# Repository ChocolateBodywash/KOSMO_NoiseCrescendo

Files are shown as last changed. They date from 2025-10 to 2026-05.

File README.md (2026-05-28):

## KOSMO Format Noise Crescendo

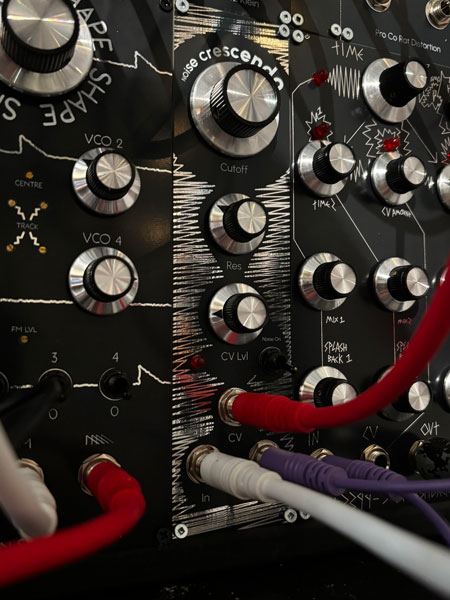
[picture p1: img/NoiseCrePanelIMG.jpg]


This is a compact module designed to produce noise crescendos for transitions, sweeps, and other crazy sounds. It’s built around a simple transistor noise circuit feeding into a low-pass filter.
The filter itself is adapted from Look Mum No Computer’s Synth Voice on a Breadboard video:

Look Mum No Computer’s Synth Voice on a Breadboard video (https://www.youtube.com/watch?v=GsTGu2V7tcU&t=2612s)

I adjusted a few component values to adjust the resonance and CV behaviour.

### Can it just be used as a filter?
Yes. With a passive summing mixer, an input jack, and an on/off switch for the noise, this becomes a straightforward low-pass filter.
LM13700s cost $4 USD on Tayda. In Canadian terms, that’s… let’s just say ‘not cheap,’ so I prefer modules that pull double duty.

---

Note: This was created by a hobbyist with no formal engineering training outside various late night YouTube binges. 
I’ve confirmed these designs to work but I make no guarantees on the design working efficiently.. or working at all.

Credit: Analog Output (Richard Holmes) for footprint libraries and front panel templates.

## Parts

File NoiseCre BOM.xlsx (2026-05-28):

Noise Crescendo
Reference | Value | Package | Qty
C1,C13 | 1uF | Box Style Film Capacitor | 2
C2,C3 | 47uF | Electrolytic Capacitor | 2
C4,C5,C6,C7,C8,C9 | 0.1uF | Ceramic Disc Capacitor | 6
C10 | 100nF | Box Style Film Capacitor | 1
C11 | 470pF | Ceramic Disc Capacitor | 1
C12 | 220pF | Ceramic Disc Capacitor | 1
D1,D2 | 1N5819 | Diode_THT:D_DO-41_SOD81_P10.16mm_Horizontal | 2
D5 | LED | LED 5.0mm | 1
E1 | Conn_01x10_Pin | 4ms_Connector:Pins_2x05_2.54mm_TH_EurorackPower_Shrouded | 1
J1 | Out | Jack_6.35mm | 1
J2 | CV In | Jack_6.35mm | 1
J3,J4 | Conn_01x06 | Connector_PinHeader_2.54mm:PinHeader_1x06_P2.54mm_Vertical | 2
J5 | In | Jack_6.35mm | 1
Q1 | BC548 | Package_TO_SOT_THT:TO-92_Inline_Wide | 1
Q2,Q3 | 2N3906 | Package_TO_SOT_THT:TO-92_Inline_Wide | 2
R1,R2,R5,R10,R13,R15,R18,R25,R29,R30 | 100K | Metal Film 1/4 Resistor | 10
R3,R4 | 10 | Metal Film 1/4 Resistor | 2
R6,R14,R16,R23,R24 | 220 | Metal Film 1/4 Resistor | 5
R7,R11,R12,R17,R21, R22,R26 | 10K | Metal Film 1/4 Resistor | 7
R8 | 470K | Metal Film 1/4 Resistor | 1
R9,R19,R27 | 1K | Metal Film 1/4 Resistor | 3
R20 | 47K | Metal Film 1/4 Resistor | 1
R28 | 6.8K | Metal Film 1/4 Resistor | 1
SW1 | SW_DPDT_x2 | DPDT-toggle-switch | 1
U1 | TL074 | DIP-14_W7.62mm_Socket_LongPads | 1
U2 | LM13700 | DIP-16_W7.62mm_Socket_LongPads | 1
VR1 | B100K Cutoff | Potentiometer_Alpha_RD901F-40-00D_Single_Vertical | 1
VR2 | B100K CV | Potentiometer_Alpha_RD901F-40-00D_Single_Vertical | 1
VR3 | B100K RES | Potentiometer_Alpha_RD901F-40-00D_Single_Vertical | 1

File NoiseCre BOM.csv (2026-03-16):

Reference | Value | Datasheet | Package | Qty
C1,C13 | 1uF | ~ | Box Style Film Capacitor | 2
C2,C3 | 47uF | ~ | Electrolytic Capacitor | 2
C4,C5,C6,C7,C8,C9 | 0.1uF | ~ | Ceramic Disc Capacitor | 6
C10 | 100nF | ~ | Box Style Film Capacitor | 1
C11 | 470pF | ~ | Ceramic Disc Capacitor | 1
C12 | 220pF | ~ | Ceramic Disc Capacitor | 1
D1,D2 | 1N5819 | http://www.vishay.com/docs/88525/1n5817.pdf | Diode_THT:D_DO-41_SOD81_P10.16mm_Horizontal | 2
D5 | LED | ~ | LED 5.0mm | 1
E1 | Conn_01x10_Pin | ~ | 4ms_Connector:Pins_2x05_2.54mm_TH_EurorackPower_Shrouded | 1
J1 | Out | ~ | Jack_6.35mm | 1
J2 | CV In | ~ | Jack_6.35mm | 1
J3,J4 | Conn_01x06 | ~ | Connector_PinHeader_2.54mm:PinHeader_1x06_P2.54mm_Vertical | 2
J5 | In | ~ | Jack_6.35mm | 1
Q1 | BC548 | https://www.onsemi.com/pub/Collateral/BC550-D.pdf | Package_TO_SOT_THT:TO-92_Inline_Wide | 1
Q2,Q3 | 2N3906 | https://www.onsemi.com/pub/Collateral/2N3906-D.PDF | Package_TO_SOT_THT:TO-92_Inline_Wide | 2
R1,R2,R5,R10,R13,R15,R18,R25,R29,R30 | 100K | ~ | Metal Film 1/4 Resistor | 10
R3,R4 | 10 | ~ | Metal Film 1/4 Resistor | 2
R6,R14,R16,R23,R24 | 220 | ~ | Metal Film 1/4 Resistor | 5
R7,R11,R12,R17,R21,R22,R26 | 10K | ~ | Metal Film 1/4 Resistor | 7
R8 | 470K | ~ | Metal Film 1/4 Resistor | 1
R9,R19,R27 | 1K | ~ | Metal Film 1/4 Resistor | 3
R20 | 47K | ~ | Metal Film 1/4 Resistor | 1
R28 | 6.8K | ~ | Metal Film 1/4 Resistor | 1
SW1 | SW_DPDT_x2 | ~ | DPDT-toggle-switch | 1
U1 | TL074 | http://www.ti.com/lit/ds/symlink/tl071.pdf | DIP-14_W7.62mm_Socket_LongPads | 1
U2 | LM13700 | http://www.ti.com/lit/ds/symlink/lm13700.pdf | DIP-16_W7.62mm_Socket_LongPads | 1
VR1 | B100K Cutoff | ~ | Potentiometer_Alpha_RD901F-40-00D_Single_Vertical | 1
VR2 | B100K CV | ~ | Potentiometer_Alpha_RD901F-40-00D_Single_Vertical | 1
VR3 | B100K RES | ~ | Potentiometer_Alpha_RD901F-40-00D_Single_Vertical | 1

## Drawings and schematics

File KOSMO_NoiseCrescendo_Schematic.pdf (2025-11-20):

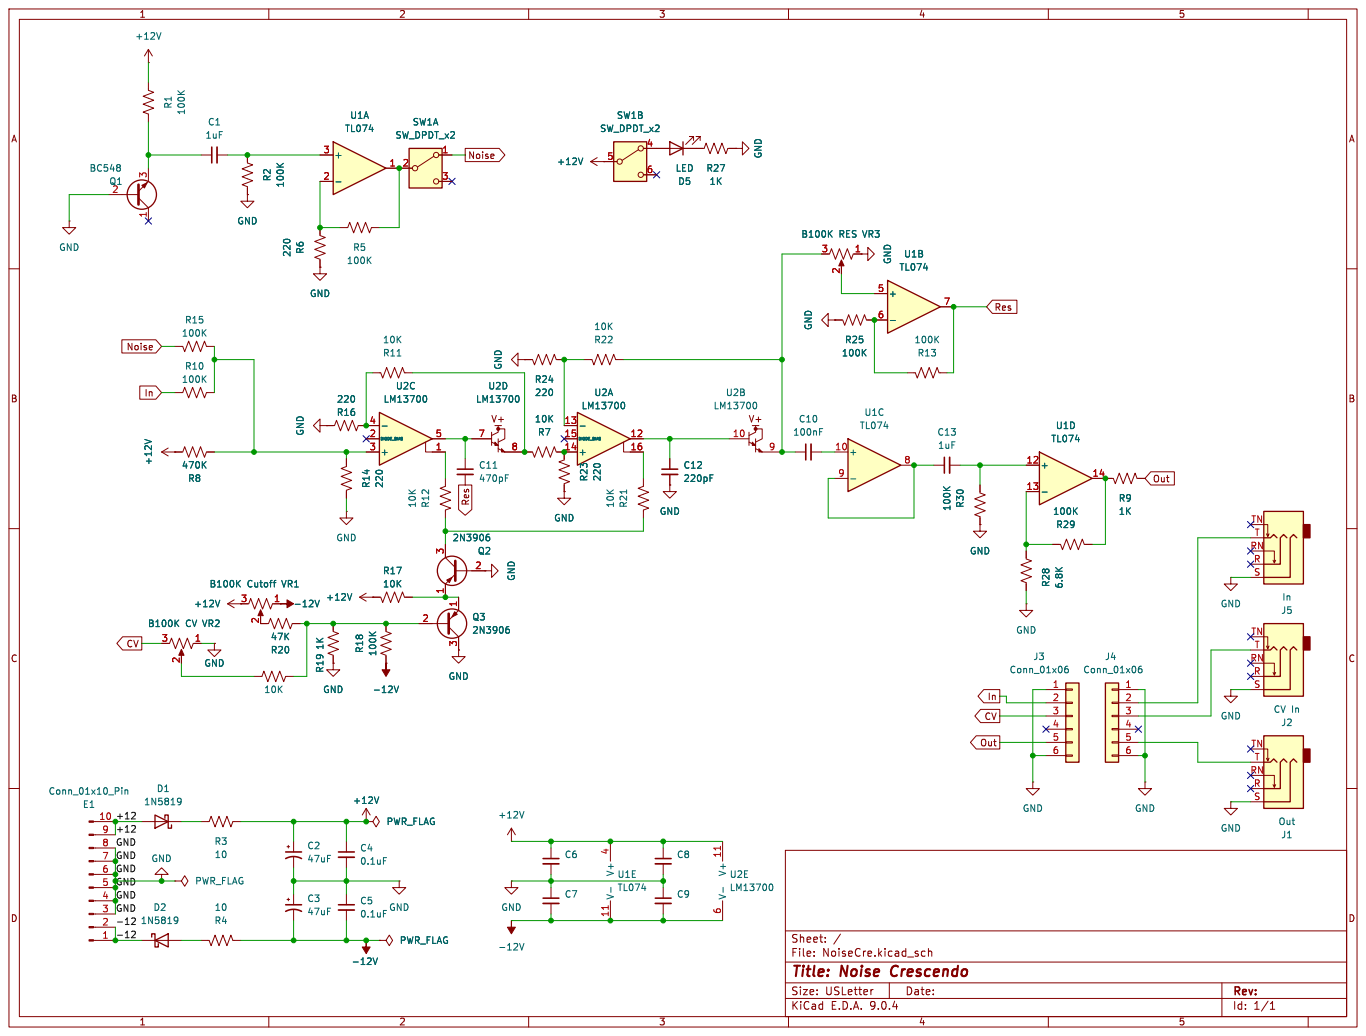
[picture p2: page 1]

File: NoiseCre.kicad_sch Sheet: /
Id: 1/1 Title: Noise Crescendo

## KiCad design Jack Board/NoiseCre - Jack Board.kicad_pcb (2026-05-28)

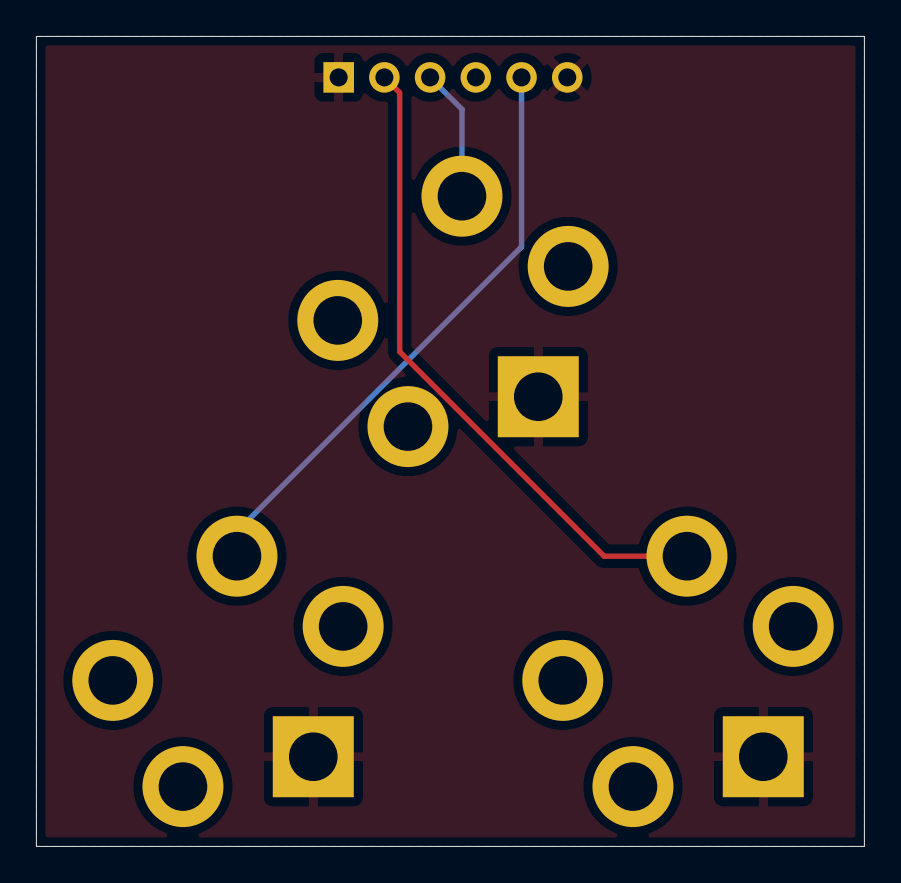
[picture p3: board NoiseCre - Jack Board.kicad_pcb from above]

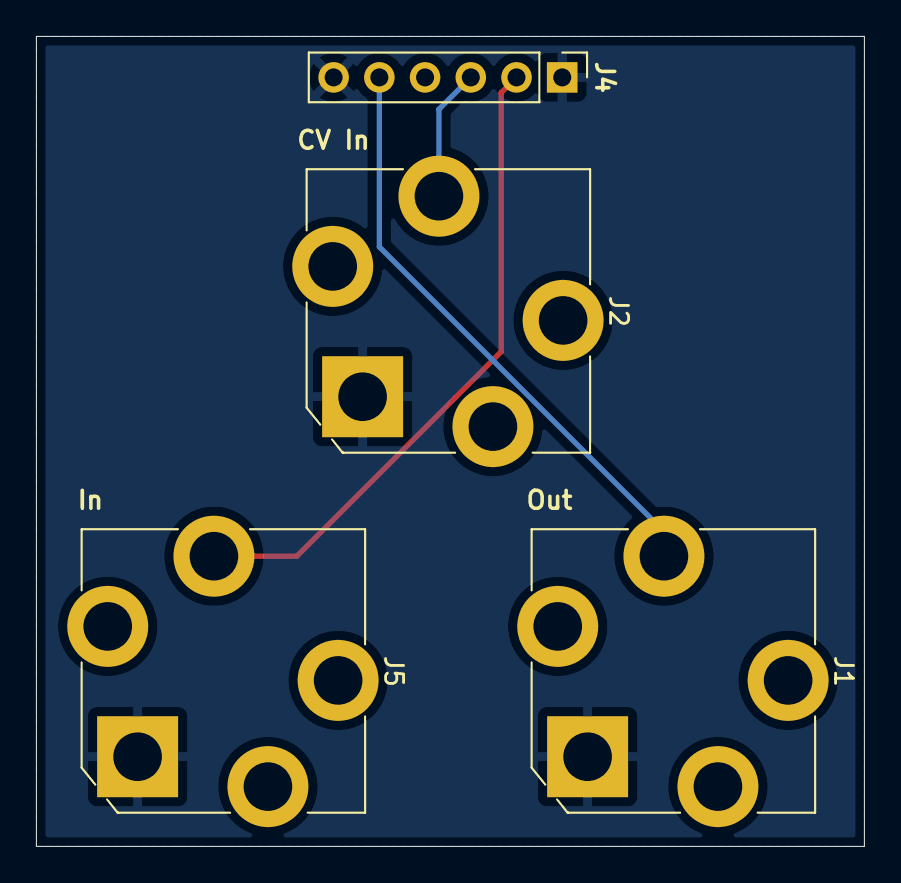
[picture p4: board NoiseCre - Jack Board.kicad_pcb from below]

Board: 2 copper layers, 46.0 x 45.0 mm, 4 parts (4 on the bottom side), 4 nets.

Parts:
J1: Out; Jack_6.35mm_PJ_629HAN
J2: CV In; Jack_6.35mm_PJ_629HAN
J4: Conn_01x06; PinHeader_1x06_P2.54mm_Vertical
J5: In; Jack_6.35mm_PJ_629HAN

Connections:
GND: J1.S, J2.S, J4.1, J4.6, J5.S
unnamed: J4.2, J5.T
unnamed: J2.T, J4.3
unnamed: J1.T, J4.5

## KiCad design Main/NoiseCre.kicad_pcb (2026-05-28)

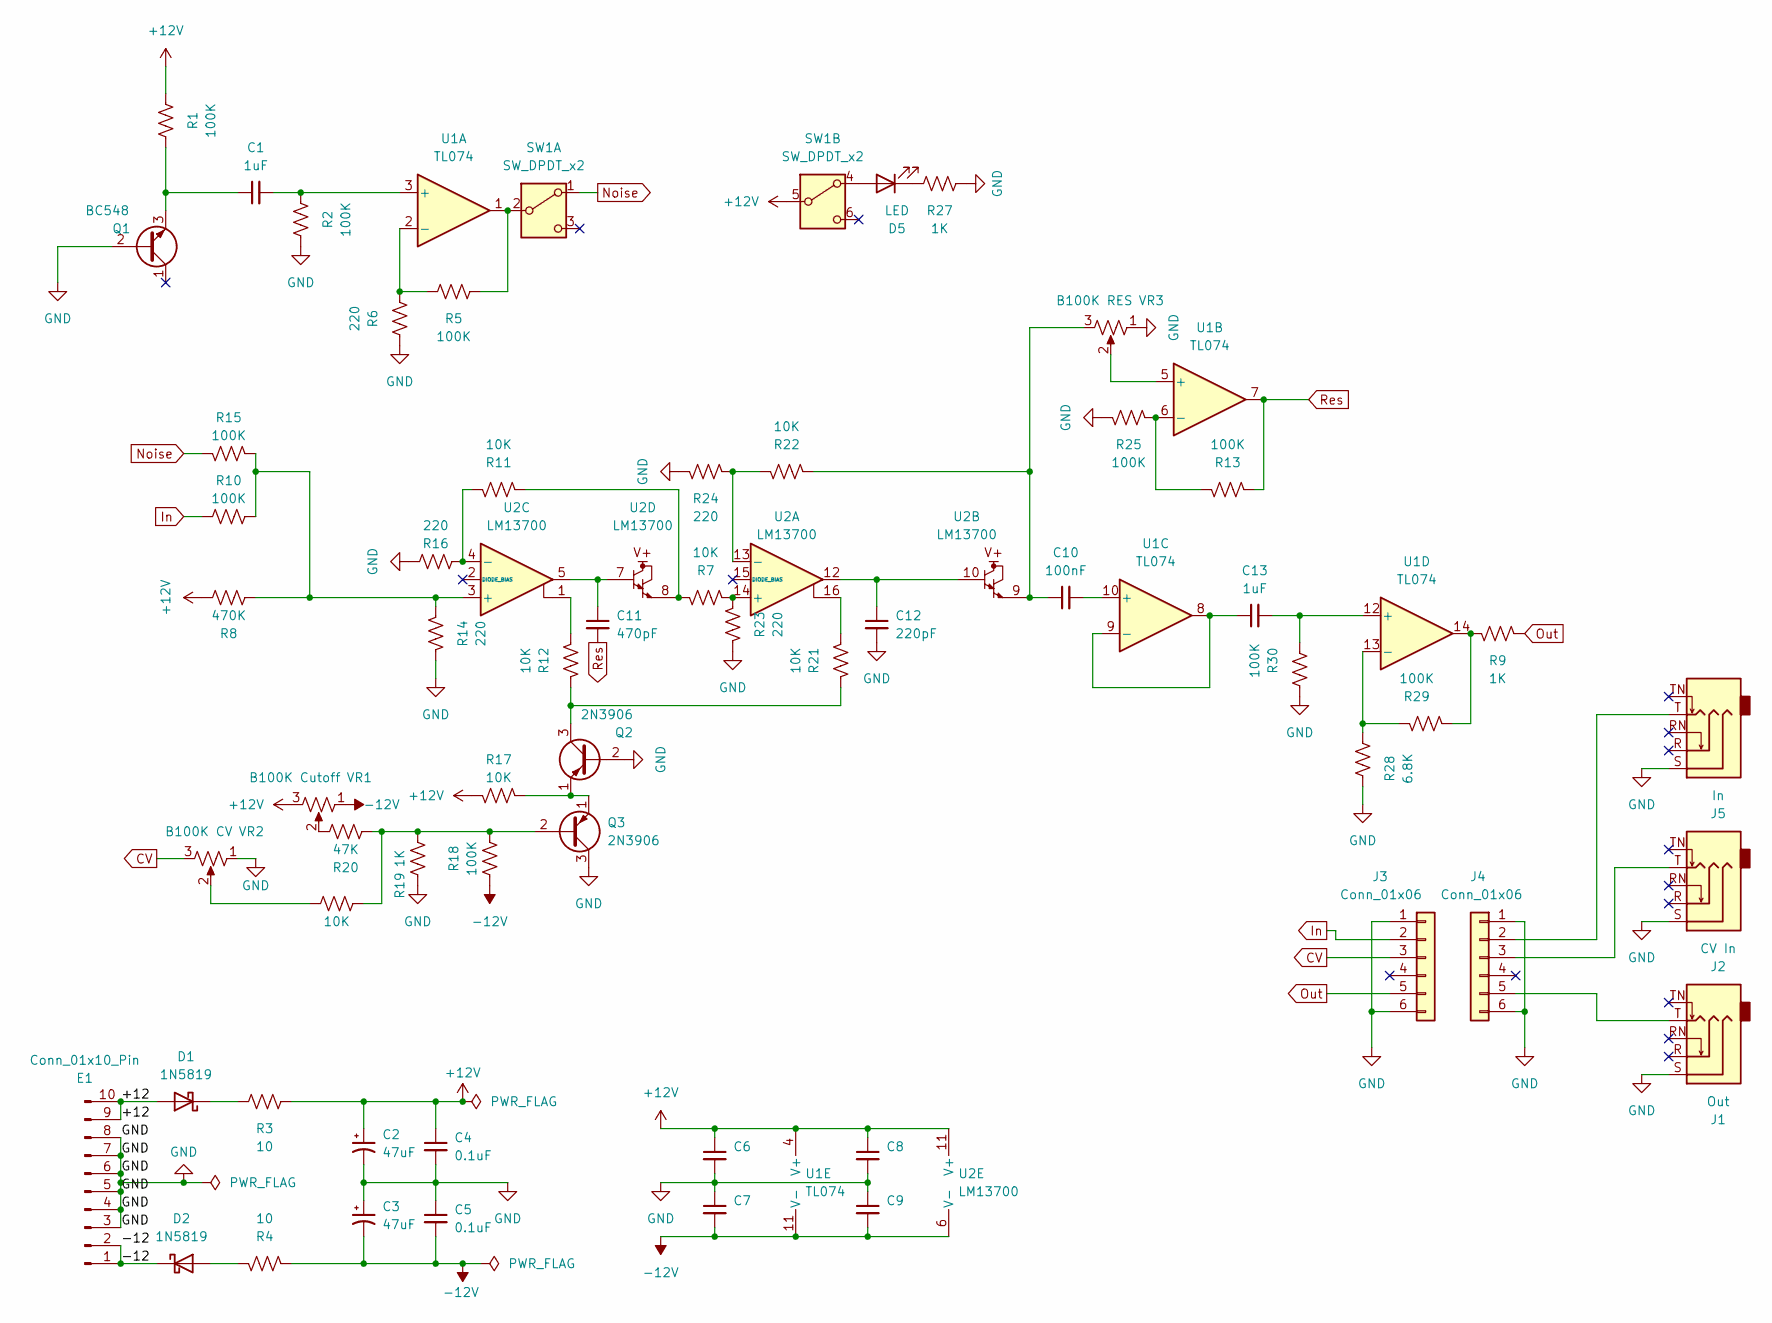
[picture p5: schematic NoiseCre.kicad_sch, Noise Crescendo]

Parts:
C1, C13: 1uF; C_Rect_L7.2mm_W5.5mm_P5.00mm_FKS2_FKP2_MKS2_MKP2
C2, C3: 47uF; CP_Radial_D5.0mm_P2.50mm
C4, C5, C6, C7, C8, C9: 0.1uF; C_Disc_D3.0mm_W1.6mm_P2.50mm
C10: 100nF; C_Rect_L7.2mm_W2.5mm_P5.00mm_FKS2_FKP2_MKS2_MKP2
C11: 470pF; C_Disc_D3.0mm_W1.6mm_P2.50mm
C12: 220pF; C_Disc_D3.0mm_W1.6mm_P2.50mm
D1, D2: 1N5819; D_DO-41_SOD81_P10.16mm_Horizontal
D5: LED; LED_D5.0mm
E1: Conn_01x10_Pin; Pins_2x05_2.54mm_TH_EurorackPower_Shrouded
J1: Out; Jack_6.35mm_PJ_629HAN
J2: CV In; Jack_6.35mm_PJ_629HAN
J3, J4: Conn_01x06; PinHeader_1x06_P2.54mm_Vertical
J5: In; Jack_6.35mm_PJ_629HAN
Q1: BC548; TO-92_Inline_Wide
Q2, Q3: 2N3906; TO-92_Inline_Wide
R1, R2, R5, R10, R13, R15, R18, R25, R29, R30: 100K; R_Axial_DIN0207_L6.3mm_D2.5mm_P10.16mm_Horizontal
R3, R4: 10; R_Axial_DIN0207_L6.3mm_D2.5mm_P10.16mm_Horizontal
R6, R14, R16, R23, R24: 220; R_Axial_DIN0207_L6.3mm_D2.5mm_P10.16mm_Horizontal
R7, R11, R12, R17, R21, R22, R26: 10K; R_Axial_DIN0207_L6.3mm_D2.5mm_P10.16mm_Horizontal
R8: 470K; R_Axial_DIN0207_L6.3mm_D2.5mm_P10.16mm_Horizontal
R9, R19, R27: 1K; R_Axial_DIN0207_L6.3mm_D2.5mm_P10.16mm_Horizontal
R20: 47K; R_Axial_DIN0207_L6.3mm_D2.5mm_P10.16mm_Horizontal
R28: 6.8K; R_Axial_DIN0207_L6.3mm_D2.5mm_P10.16mm_Horizontal
SW1: SW_DPDT_x2; DPDT-toggle-switch-1M-seriesx
U1: TL074; DIP-14_W7.62mm_Socket_LongPads
U2: LM13700; DIP-16_W7.62mm_Socket_LongPads
VR1: B100K Cutoff; Potentiometer_Alpha_RD901F-40-00D_Single_Vertical
VR2: B100K CV; Potentiometer_Alpha_RD901F-40-00D_Single_Vertical
VR3: B100K RES; Potentiometer_Alpha_RD901F-40-00D_Single_Vertical

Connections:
+12V: C2.1, C4.1, C6.1, C8.1, R1.2, R3.2, R8.2, R17.2, SW1.5 (B), U1.4 (V+), U2.11 (V+), VR1.3
-12V: C3.2, C5.2, C7.2, C9.2, R4.2, R18.1, U1.11 (V-), U2.6 (V-), VR1.1
/+12: D1.2 (A), E1.9, E1.10
/-12: D2.1 (K), E1.1, E1.2
CV: J3.3, VR2.3
GND: C2.2, C3.1, C4.2, C5.1, C6.2, C7.1, C8.2, C9.1, C12.2, E1.3, E1.4, E1.5, E1.6, E1.7, E1.8, J1.S, J2.S, J3.1, J3.6, J4.1, J4.6, J5.S, Q1.2 (B), Q2.2 (B), Q3.3 (C), R2.1, R6.2, R14.2, R16.2, R19.1, R23.2, R24.2, R25.2, R27.2, R28.1, R30.2, VR2.1, VR3.1
In: J3.2, R10.1
unnamed: C10.1, R22.2, U2.9, VR3.3
unnamed: C11.1, U2.5, U2.7
unnamed: C12.1, U2.10, U2.12
unnamed: D1.1 (K), R3.1
unnamed: D2.2 (A), R4.1
unnamed: D5.2 (A), SW1.4 (A)
unnamed: D5.1 (K), R27.1
unnamed: J1.T, J4.5
unnamed: J2.T, J4.3
unnamed: J4.2, J5.T
unnamed: C1.1, Q1.3 (E), R1.1
unnamed: Q2.3 (C), R12.1, R21.1
unnamed: Q2.1 (E), Q3.1 (E), R17.1
unnamed: Q3.2 (B), R18.2, R19.2, R20.1, R26.1
unnamed: R7.1, R11.2, U2.8
unnamed: R12.2, U2.1
unnamed: R20.2, VR1.2
unnamed: R21.2, U2.16
unnamed: R26.2, VR2.2
unnamed: R9.2, R29.2, U1.14
unnamed: R5.2, SW1.2 (B), U1.1
unnamed: C1.2, R2.2, U1.3 (+)
unnamed: R5.1, R6.1, U1.2 (-)
unnamed: U1.5 (+), VR3.2
unnamed: R13.1, R25.1, U1.6 (-)
unnamed: C10.2, U1.10 (+)
unnamed: C13.1, U1.8, U1.9 (-)
unnamed: C13.2, R30.1, U1.12 (+)
unnamed: R28.2, R29.1, U1.13 (-)
unnamed: R7.2, R23.1, U2.14 (+)
unnamed: R22.1, R24.1, U2.13 (-)
unnamed: R8.1, R10.2, R14.1, R15.1, U2.3 (+)
unnamed: R11.1, R16.1, U2.4 (-)
Noise: R15.2, SW1.1 (A)
Out: J3.5, R9.1
Res: C11.2, R13.2, U1.7

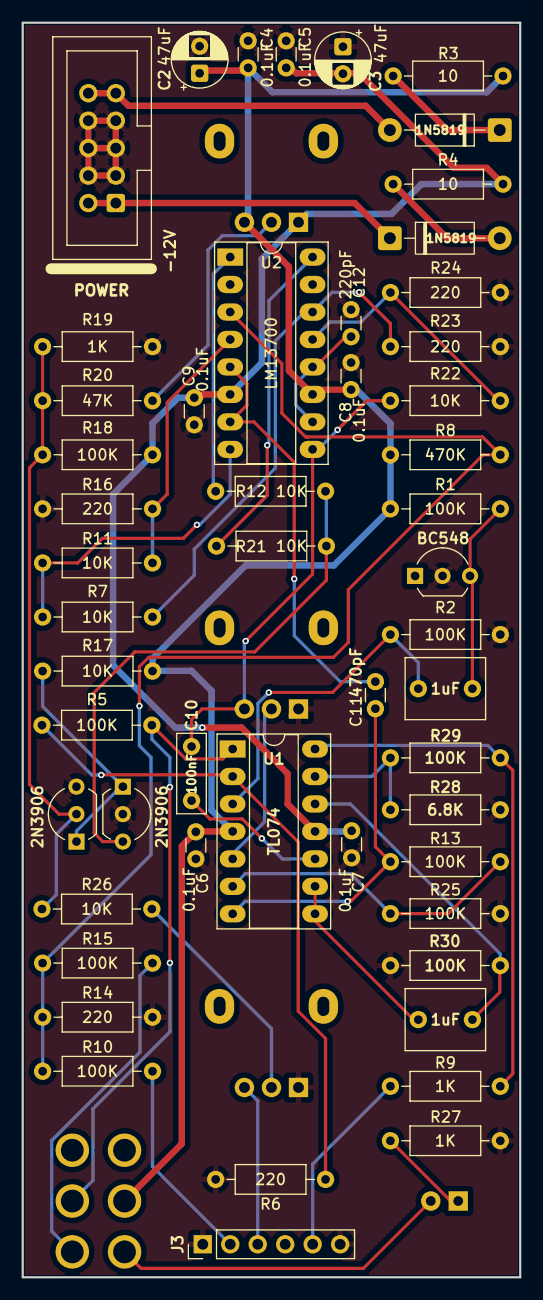
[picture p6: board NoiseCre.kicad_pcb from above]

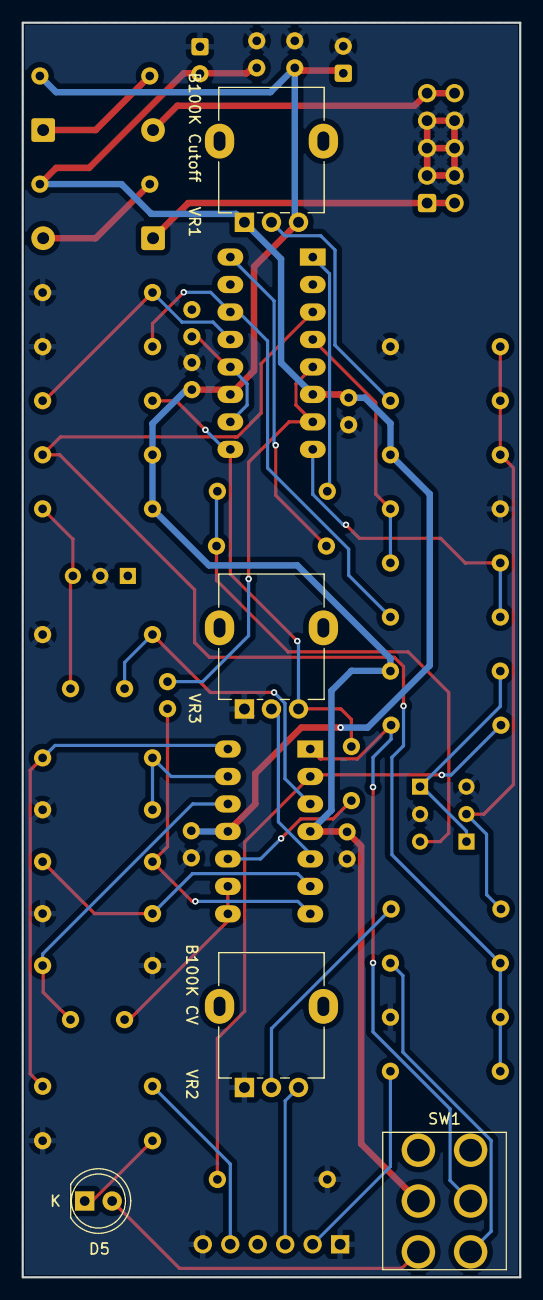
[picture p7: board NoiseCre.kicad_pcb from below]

Board: 2 copper layers, 46.0 x 116.0 mm, 57 parts (5 on the bottom side), 40 nets.

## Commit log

2025-10-05 Panel change
    [Noise Cres - Front Panel.kicad_pcb]
2025-10-24 Create NoiseCre BOM.csv
    [NoiseCre BOM.csv]
2025-10-29 Upload Schematics
    [NoiseCre.kicad_sch]
2025-11-20 Updated gain output
    [NoiseCre.kicad_pcb, NoiseCre.kicad_sch]
2026-03-16 Update NoiseCre BOM.csv
    [NoiseCre BOM.csv]
2026-05-28 Gerbers Added
    [Noise Cres - Front Panel.kicad_pcb, NoiseCre - Jack Board.kicad_pcb, NoiseCre BOM.xlsx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]
